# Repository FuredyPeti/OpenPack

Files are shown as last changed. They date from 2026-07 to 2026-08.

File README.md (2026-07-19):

# OpenPack

**An open-source, field-serviceable USB-C PD power bank built around standard 18650 cells.**

OpenPack is a portable battery pack designed to be repaired, not replaced. Instead of a sealed pouch cell, it holds six user-replaceable 18650 cells in a 2P3S configuration, so when capacity fades you swap cells instead of throwing the whole device away. It's built around a single PCB (`BATMOD_V1p0`) housed in a 3D-printed, military-styled enclosure with a CNC-machined aluminum front panel.

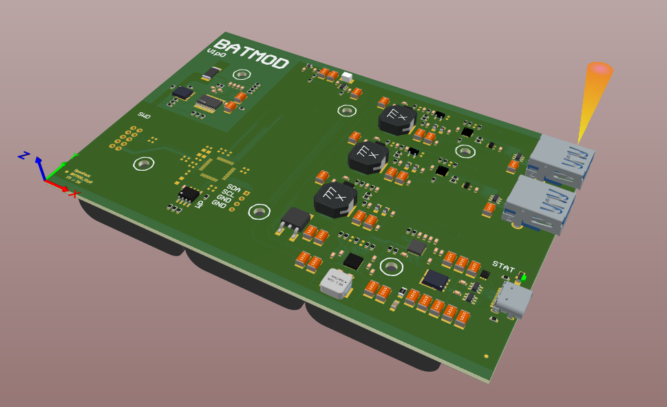
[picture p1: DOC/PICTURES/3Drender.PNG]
OpenPack_BATMOD_V1p0


---

## Highlights

- **6x 18650 cells in swappable holders** — 2P3S pack, use any cell you like
- **100 W USB-C PD port** — sink or source up to 20 V / 5 A
- **Two fixed 5 V / 2 A USB-A ports** for everyday device charging
- **Dedicated hardware balancing and protection** for the 3S pack
- **Single-board design** (`BATMOD_V1p0`) — everything lives on one PCB
- **3D-printed enclosure** with a machined aluminum port plate
- **Fully open source** — schematics, PCB, and mechanical files included

---

## Specifications

| | |
|---|---|
| Cell configuration | 2P3S (6x 18650, user-supplied, socketed in holders) |
| USB-C port | USB PD, sink/source up to 20 V @ 5 A (100 W) |
| USB-A port 1 | Fixed 5 V, up to 2 A |
| USB-A port 2 | Fixed 5 V, up to 2 A |
| Charging input | USB-C only (USB-A ports are output-only) |
| PCB | BATMOD_V1p0 | 94mm x 140mm
| Enclosure | 3D-printed body, CNC-machined aluminum front panel |

---

## Electronics

### USB-C PD port — TPS25751SRSMR

The USB-C port is driven by TI's **TPS25751**, a standalone USB Type-C and Power Delivery controller with integrated power switches. It's USB-IF certified for PD 3.1 and handles the full Type-C/PD negotiation stack on its own, so the port can act as either a sink or a source and negotiate up to 20 V at 5 A (100 W). The chip also includes dead-battery boot support (it can power itself from VBUS with no cell installed) and integrated protection — reverse current, over/undervoltage, and inrush current limiting — on its power paths. It also natively integrates control signaling for external battery-charger ICs like the BQ25798 below, which is how it hands off charging duties to the rest of the board.

### Battery charging — BQ25798RQMR

Charging is managed by the **BQ25798**, a 5 A, I2C-controlled buck-boost charger for 1- to 4-cell Li-ion/Li-poly packs. It runs a wide 3.6 V–24 V input range, is USB PD-compliant, and automatically switches between buck, boost, and buck-boost modes depending on input and battery voltage — useful given how much VBUS can swing across different PD sources. It also includes input current optimization (ICO) and MPPT for oddball or current-limited sources.

### Battery protection & cell balancing — BQ7791500PWT (BQ77915)

Pack-level safety and balancing is handled by the **BQ77915**, a stackable primary protector purpose-built for 3S–5S packs. It runs autonomous passive cell balancing (up to 50 mA) without needing a microcontroller, on top of the usual overvoltage/undervoltage/overcurrent/overtemperature protection suite — matched here to the pack's 3S configuration.

### USB-A output ports — TPS2547RTER

The two USB-A ports are each driven by a **TPS2547**, a USB charging port controller with an integrated 3 A power switch and D+/D− load detection. It presents the correct charging signatures (BC1.2 and common non-BC1.2 legacy schemes) so phones, tablets, and other USB-A devices auto-detect the port and charge at their expected rate. On OpenPack these are configured for a fixed 5 V output, capped at 2 A, and are output-only — they cannot be used to charge the internal pack.

---

## Mechanical design

Everything lives on one board — **BATMOD_V1p0** — with the six 18650 holders mounted on one side of the PCB. The board drops into a 3D-printed enclosure styled after military-grade equipment, and the front plate, where the USB-C and both USB-A ports live, is CNC-machined from aluminum rather than printed, both for durability at the connectors and for the finish.

---

## Repository contents

- `/HW` — schematics and PCB design files for BATMOD_V1p0
- `/MECH` — 3D-printable enclosure and aluminum front-plate machining files
- `/SYS` — assembly notes and reference material

---

## Safety note

This project involves user-configurable Li-ion packs and mains-adjacent charge currents. If you build one, use protected/authentic cells, verify balancing and protection behavior before first full charge, and don't leave a pack charging unattended until you've validated your build.

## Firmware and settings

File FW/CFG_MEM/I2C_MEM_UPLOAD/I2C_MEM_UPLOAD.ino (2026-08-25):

#include <Wire.h>

const char tps25750x_fullFlash_i2c_array[] = {
0x00, 0x08, 0x00, 0x00, 0xff, 0xff, 0xff, 0xff, 0xff, 0xff, 0xff, 0xff, 0xff, 0xff, 0xff, 0xff, 
0xff, 0xff, 0xff, 0xff, 0xff, 0xff, 0xff, 0xff, 0xff, 0xff, 0xff, 0xff, 0xff, 0xff, 0xff, 0xff, 
0xff, 0xff, 0xff, 0xff, 0xff, 0xff, 0xff, 0xff, 0xff, 0xff, 0xff, 0xff, 0xff, 0xff, 0xff, 0xff, 
0xff, 0xff, 0xff, 0xff, 0xff, 0xff, 0xff, 0xff, 0xff, 0xff, 0xff, 0xff, 0xff, 0xff, 0xff, 0xff, 
0xff, 0xff, 0xff, 0xff, 0xff, 0xff, 0xff, 0xff, 0xff, 0xff, 0xff, 0xff, 0xff, 0xff, 0xff, 0xff, 
0xff, 0xff, 0xff, 0xff, 0xff, 0xff, 0xff, 0xff, 0xff, 0xff, 0xff, 0xff, 0xff, 0xff, 0xff, 0xff, 
0xff, 0xff, 0xff, 0xff, 0xff, 0xff, 0xff, 0xff, 0xff, 0xff, 0xff, 0xff, 0xff, 0xff, 0xff, 0xff, 
0xff, 0xff, 0xff, 0xff, 0xff, 0xff, 0xff, 0xff, 0xff, 0xff, 0xff, 0xff, 0xff, 0xff, 0xff, 0xff, 
0xff, 0xff, 0xff, 0xff, 0xff, 0xff, 0xff, 0xff, 0xff, 0xff, 0xff, 0xff, 0xff, 0xff, 0xff, 0xff, 
0xff, 0xff, 0xff, 0xff, 0xff, 0xff, 0xff, 0xff, 0xff, 0xff, 0xff, 0xff, 0xff, 0xff, 0xff, 0xff, 
0xff, 0xff, 0xff, 0xff, 0xff, 0xff, 0xff, 0xff, 0xff, 0xff, 0xff, 0xff, 0xff, 0xff, 0xff, 0xff, 
0xff, 0xff, 0xff, 0xff, 0xff, 0xff, 0xff, 0xff, 0xff, 0xff, 0xff, 0xff, 0xff, 0xff, 0xff, 0xff, 
0xff, 0xff, 0xff, 0xff, 0xff, 0xff, 0xff, 0xff, 0xff, 0xff, 0xff, 0xff, 0xff, 0xff, 0xff, 0xff, 
0xff, 0xff, 0xff, 0xff, 0xff, 0xff, 0xff, 0xff, 0xff, 0xff, 0xff, 0xff, 0xff, 0xff, 0xff, 0xff, 
0xff, 0xff, 0xff, 0xff, 0xff, 0xff, 0xff, 0xff, 0xff, 0xff, 0xff, 0xff, 0xff, 0xff, 0xff, 0xff, 
0xff, 0xff, 0xff, 0xff, 0xff, 0xff, 0xff, 0xff, 0xff, 0xff, 0xff, 0xff, 0xff, 0xff, 0xff, 0xff, 
0xff, 0xff, 0xff, 0xff, 0xff, 0xff, 0xff, 0xff, 0xff, 0xff, 0xff, 0xff, 0xff, 0xff, 0xff, 0xff, 
0xff, 0xff, 0xff, 0xff, 0xff, 0xff, 0xff, 0xff, 0xff, 0xff, 0xff, 0xff, 0xff, 0xff, 0xff, 0xff, 
0xff, 0xff, 0xff, 0xff, 0xff, 0xff, 0xff, 0xff, 0xff, 0xff, 0xff, 0xff, 0xff, 0xff, 0xff, 0xff, 
0xff, 0xff, 0xff, 0xff, 0xff, 0xff, 0xff, 0xff, 0xff, 0xff, 0xff, 0xff, 0xff, 0xff, 0xff, 0xff, 
0xff, 0xff, 0xff, 0xff, 0xff, 0xff, 0xff, 0xff, 0xff, 0xff, 0xff, 0xff, 0xff, 0xff, 0xff, 0xff, 
0xff, 0xff, 0xff, 0xff, 0xff, 0xff, 0xff, 0xff, 0xff, 0xff, 0xff, 0xff, 0xff, 0xff, 0xff, 0xff, 
0xff, 0xff, 0xff, 0xff, 0xff, 0xff, 0xff, 0xff, 0xff, 0xff, 0xff, 0xff, 0xff, 0xff, 0xff, 0xff, 
0xff, 0xff, 0xff, 0xff, 0xff, 0xff, 0xff, 0xff, 0xff, 0xff, 0xff, 0xff, 0xff, 0xff, 0xff, 0xff, 
0xff, 0xff, 0xff, 0xff, 0xff, 0xff, 0xff, 0xff, 0xff, 0xff, 0xff, 0xff, 0xff, 0xff, 0xff, 0xff, 
0xff, 0xff, 0xff, 0xff, 0xff, 0xff, 0xff, 0xff, 0xff, 0xff, 0xff, 0xff, 0xff, 0xff, 0xff, 0xff, 
0xff, 0xff, 0xff, 0xff, 0xff, 0xff, 0xff, 0xff, 0xff, 0xff, 0xff, 0xff, 0xff, 0xff, 0xff, 0xff, 
0xff, 0xff, 0xff, 0xff, 0xff, 0xff, 0xff, 0xff, 0xff, 0xff, 0xff, 0xff, 0xff, 0xff, 0xff, 0xff, 
0xff, 0xff, 0xff, 0xff, 0xff, 0xff, 0xff, 0xff, 0xff, 0xff, 0xff, 0xff, 0xff, 0xff, 0xff, 0xff, 
0xff, 0xff, 0xff, 0xff, 0xff, 0xff, 0xff, 0xff, 0xff, 0xff, 0xff, 0xff, 0xff, 0xff, 0xff, 0xff, 
0xff, 0xff, 0xff, 0xff, 0xff, 0xff, 0xff, 0xff, 0xff, 0xff, 0xff, 0xff, 0xff, 0xff, 0xff, 0xff, 
0xff, 0xff, 0xff, 0xff, 0xff, 0xff, 0xff, 0xff, 0xff, 0xff, 0xff, 0xff, 0xff, 0xff, 0xff, 0xff, 
0xff, 0xff, 0xff, 0xff, 0xff, 0xff, 0xff, 0xff, 0xff, 0xff, 0xff, 0xff, 0xff, 0xff, 0xff, 0xff, 
0xff, 0xff, 0xff, 0xff, 0xff, 0xff, 0xff, 0xff, 0xff, 0xff, 0xff, 0xff, 0xff, 0xff, 0xff, 0xff, 
0xff, 0xff, 0xff, 0xff, 0xff, 0xff, 0xff, 0xff, 0xff, 0xff, 0xff, 0xff, 0xff, 0xff, 0xff, 0xff, 
0xff, 0xff, 0xff, 0xff, 0xff, 0xff, 0xff, 0xff, 0xff, 0xff, 0xff, 0xff, 0xff, 0xff, 0xff, 0xff, 
0xff, 0xff, 0xff, 0xff, 0xff, 0xff, 0xff, 0xff, 0xff, 0xff, 0xff, 0xff, 0xff, 0xff, 0xff, 0xff, 
0xff, 0xff, 0xff, 0xff, 0xff, 0xff, 0xff, 0xff, 0xff, 0xff, 0xff, 0xff, 0xff, 0xff, 0xff, 0xff, 
0xff, 0xff, 0xff, 0xff, 0xff, 0xff, 0xff, 0xff, 0xff, 0xff, 0xff, 0xff, 0xff, 0xff, 0xff, 0xff, 
0xff, 0xff, 0xff, 0xff, 0xff, 0xff, 0xff, 0xff, 0xff, 0xff, 0xff, 0xff, 0xff, 0xff, 0xff, 0xff, 
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


#define EEPROM_I2C_ADDRESS 0x50  // I2C address of EEPROM
#define PAGE_SIZE 64             // Page size in bytes
#define TOTAL_SIZE 32768         // Total EEPROM size (256Kbit = 32KB) - adjust as needed
#define WRITE_DELAY 30           // Write cycle time in ms (typ. 5ms, typ. 10ms max)

// Configuration
#define ENABLE_VERIFICATION true
#define ENABLE_VERBOSE_LOGGING true

// ============================================================================
// EEPROM Write Function - Handles page boundaries
// ============================================================================
bool EEPROM_WriteBytes(uint16_t memoryAddress, uint8_t* data, uint16_t length) {
    uint16_t bytesWritten = 0;

    while (bytesWritten < length) {
        // Calculate remaining space in current page
        uint16_t pageOffset = memoryAddress % PAGE_SIZE;
        uint16_t maxWriteInPage = PAGE_SIZE - pageOffset;

        // Determine how many bytes to write in this iteration
        uint16_t bytesToTransfer = length - bytesWritten;
        if (bytesToTransfer > maxWriteInPage) {
            bytesToTransfer = maxWriteInPage;
        }

        // Start I2C transmission
        Wire.beginTransmission(EEPROM_I2C_ADDRESS);

        // Send 16-bit memory address (MSB first, then LSB)
        Wire.write((uint8_t)(memoryAddress >> 8));
        Wire.write((uint8_t)(memoryAddress & 0xFF));

        // Send data bytes
        for (uint16_t i = 0; i < bytesToTransfer; i++) {
            Wire.write(data[bytesWritten + i]);
        }

        // End transmission and check for errors
        uint8_t error = Wire.endTransmission();
        if (error != 0) {
            Serial.print("I2C Error at address 0x");
            Serial.print(memoryAddress, HEX);
            Serial.print(": ");
            printI2CError(error);
            return false;
        }

        // CRITICAL: Wait for internal write cycle to complete
        delay(WRITE_DELAY);

        // Update counters
        memoryAddress += bytesToTransfer;
        bytesWritten += bytesToTransfer;
    }

    return true;
}

// ============================================================================
// EEPROM Read Function - Verify written data
// ============================================================================
bool EEPROM_ReadBytes(uint16_t memoryAddress, uint8_t* data, uint16_t length) {
    uint16_t bytesRead = 0;

    while (bytesRead < length) {
        // Set the memory address we want to read from
        Wire.beginTransmission(EEPROM_I2C_ADDRESS);
        Wire.write((uint8_t)(memoryAddress >> 8));
        Wire.write((uint8_t)(memoryAddress & 0xFF));
        uint8_t error = Wire.endTransmission();

        if (error != 0) {
            Serial.print("I2C Error during read address setup at 0x");
            Serial.print(memoryAddress, HEX);
            Serial.print(": ");
            printI2CError(error);
            return false;
        }

        // Read up to 32 bytes per request (many I2C devices have small RX buffers)
        uint16_t bytesToRead = length - bytesRead;
        if (bytesToRead > 32) {
            bytesToRead = 32;
        }

        // Request data
        uint8_t bytesAvailable = Wire.requestFrom(EEPROM_I2C_ADDRESS, (int)bytesToRead);

        if (bytesAvailable != bytesToRead) {
            Serial.print("I2C Read mismatch at 0x");
            Serial.print(memoryAddress, HEX);
            Serial.print(" - requested ");
            Serial.print(bytesToRead);
            Serial.print(" got ");
            Serial.println(bytesAvailable);
            return false;
        }

        // Read bytes into buffer
        for (uint16_t i = 0; i < bytesAvailable; i++) {
            data[bytesRead + i] = Wire.read();
        }

        bytesRead += bytesAvailable;
        memoryAddress += bytesAvailable;
    }

    return true;
}

// ============================================================================
// Verification Function - Compare written data with original
// ============================================================================
bool EEPROM_VerifyBytes(uint16_t memoryAddress, uint8_t* expectedData, uint16_t length) {
    uint8_t readBuffer[64];
    uint16_t bytesVerified = 0;

    while (bytesVerified < length) {
        uint16_t bytesToCheck = length - bytesVerified;
        if (bytesToCheck > 64) {
            bytesToCheck = 64;
        }

        // Read from EEPROM
        if (!EEPROM_ReadBytes(memoryAddress + bytesVerified, readBuffer, bytesToCheck)) {
            Serial.print("Verification read failed at address 0x");
            Serial.println(memoryAddress + bytesVerified, HEX);
            return false;
        }

        // Compare bytes
        for (uint16_t i = 0; i < bytesToCheck; i++) {
            if (readBuffer[i] != expectedData[bytesVerified + i]) {
                Serial.print("Verification MISMATCH at address 0x");
                Serial.print(memoryAddress + bytesVerified + i, HEX);
                Serial.print(" - Expected: 0x");
                Serial.print(expectedData[bytesVerified + i], HEX);
                Serial.print(" Got: 0x");
                Serial.println(readBuffer[i], HEX);
                return false;
            }
        }

        bytesVerified += bytesToCheck;
    }

    return true;
}

// ============================================================================
// Utility Functions
// ============================================================================
void printI2CError(uint8_t error) {
    switch(error) {
        case 0: Serial.println("Success"); break;
        case 1: Serial.println("Data too long for buffer"); break;
        case 2: Serial.println("NACK on address"); break;
        case 3: Serial.println("NACK on data"); break;
        case 4: Serial.println("Other error"); break;
        case 5: Serial.println("Timeout"); break;
        default: Serial.println("Unknown error"); break;
    }
}

void printHex(uint8_t value) {
    if (value < 0x10) Serial.print("0");
    Serial.print(value, HEX);
}

// ============================================================================
// Setup - Flash the EEPROM with data and verify
// ============================================================================
void setup() {
    Serial.begin(115200);
    delay(500); // Wait for serial to initialize

    Serial.println("\n=== ESP32 EEPROM I2C Programmer ===");
    Serial.println("Initializing I2C...");

    Wire.begin(21, 22); // SDA = GPIO 21, SCL = GPIO 22
    Wire.setClock(400000); // 400 kHz I2C speed

    // Calculate total data to write
    size_t dataSize = sizeof(tps25750x_fullFlash_i2c_array) / sizeof(tps25750x_fullFlash_i2c_array[0]);
    uint16_t totalPages = (dataSize + PAGE_SIZE - 1) / PAGE_SIZE; // Round up

    Serial.print("Data size: ");
    Serial.print(dataSize);
    Serial.println(" bytes");
    Serial.print("Pages to write: ");
    Serial.println(totalPages);
    Serial.println();

    uint16_t regaddress = 0;
    uint8_t Data[PAGE_SIZE];
    uint16_t pageCount = 0;
    uint32_t startTime = millis();

    // ========== WRITE PHASE ==========
    Serial.println("--- WRITE PHASE ---");

    for (pageCount = 0; pageCount < totalPages; pageCount++) {
        // Determine how many bytes to write in this page
        uint16_t bytesToWrite = dataSize - regaddress;
        if (bytesToWrite > PAGE_SIZE) {
            bytesToWrite = PAGE_SIZE;
        }

        // Copy data to temporary buffer
        for (int i = 0; i < bytesToWrite; i++) {
            Data[i] = (uint8_t)tps25750x_fullFlash_i2c_array[regaddress + i];
        }

        // Write page
        if (EEPROM_WriteBytes(regaddress, Data, bytesToWrite)) {
            if (ENABLE_VERBOSE_LOGGING) {
                Serial.print("Page ");
                Serial.print(pageCount + 1);
                Serial.print("/");
                Serial.print(totalPages);
                Serial.print(" written at address 0x");
                Serial.print(regaddress, HEX);
                Serial.print(" (");
                Serial.print(bytesToWrite);
                Serial.println(" bytes)");
            }
        } else {
            Serial.print("ERROR writing page ");
            Serial.print(pageCount + 1);
            Serial.print(" at address 0x");
            Serial.println(regaddress, HEX);
            goto errorExit;
        }

        regaddress += bytesToWrite;
    }

    Serial.println("Write phase completed!\n");

    // ========== VERIFICATION PHASE ==========
    if (ENABLE_VERIFICATION) {
        Serial.println("--- VERIFICATION PHASE ---");
        regaddress = 0;
        uint16_t failedPages = 0;

        for (pageCount = 0; pageCount < totalPages; pageCount++) {
            uint16_t bytesToVerify = dataSize - (pageCount * PAGE_SIZE);
            if (bytesToVerify > PAGE_SIZE) {
                bytesToVerify = PAGE_SIZE;
            }

            // Get original data
            for (int i = 0; i < bytesToVerify; i++) {
                Data[i] = (uint8_t)tps25750x_fullFlash_i2c_array[regaddress + i];
            }

            // Verify
            if (EEPROM_VerifyBytes(regaddress, Data, bytesToVerify)) {
                if (ENABLE_VERBOSE_LOGGING) {
                    Serial.print("Page ");
                    Serial.print(pageCount + 1);
                    Serial.print("/");
                    Serial.print(totalPages);
                    Serial.print(" verified at address 0x");
                    Serial.println(regaddress, HEX);
                }
            } else {
                Serial.print("VERIFICATION FAILED on page ");
                Serial.print(pageCount + 1);
                Serial.print(" at address 0x");
                Serial.println(regaddress, HEX);
                failedPages++;
            }

            regaddress += bytesToVerify;
        }

        Serial.println();
        if (failedPages == 0) {
            Serial.println("✓ ALL PAGES VERIFIED SUCCESSFULLY!");
        } else {
            Serial.print("✗ ");
            Serial.print(failedPages);
            Serial.println(" page(s) failed verification!");
            goto errorExit;
        }
    }

    // ========== SUCCESS ==========
    {
        uint32_t elapsed = millis() - startTime;
        Serial.println("\n=== PROGRAMMING COMPLETE ===");
        Serial.print("Total time: ");
        Serial.print(elapsed);
        Serial.println(" ms");
        Serial.print("Data rate: ");
        Serial.print((dataSize * 1000) / elapsed);
        Serial.println(" bytes/sec");
    }
    return;

    // ========== ERROR EXIT ==========
    errorExit:
    Serial.println("\n✗ PROGRAMMING FAILED!");
    Serial.println("Check:");
    Serial.println("  - I2C address (default 0x50)");
    Serial.println("  - I2C pull-up resistors (usually 4.7kΩ)");
    Serial.println("  - EEPROM chip connections");
    Serial.println("  - EEPROM write protection (WP pin)");
}

void loop() {
    // Empty - all work done in setup
}

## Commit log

2026-07-12 First HW commit, started to work on SCH
    [OpenPack_BATMOD_V1p0.PrjPcb, OpenPack_BATMOD_V1p0_CHRG.SchDoc, OpenPack_BATMOD_V1p0_FRP.SchDoc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]
2026-07-13 Working on manager, battery, cell balancer, USBA ports and main page
    [OpenPack_BATMOD_V1p0.PrjPcb, OpenPack_BATMOD_V1p0_BAT.SchDoc, OpenPack_BATMOD_V1p0_CHRG.SchDoc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]
2026-07-14 Overall schematic progress 90%
    [OpenPack_BATMOD_V1p0_BAT.SchDoc, OpenPack_BATMOD_V1p0_CHRG.SchDoc, OpenPack_BATMOD_V1p0_MAIN.SchDoc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]
2026-07-15 SCH finishing, PCB start
    [OpenPack_BATMOD_V1p0.PrjPcb, OpenPack_BATMOD_V1p0_BAT.SchDoc, OpenPack_BATMOD_V1p0_CHRG.SchDoc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]
2026-07-15 More work on PCB
    [OpenPack_BATMOD_V1p0.PrjPcb, OpenPack_BATMOD_V1p0_CHRG.SchDoc, OpenPack_BATMOD_V1p0_PWR.SchDoc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]
2026-07-16 PCB progress
    [OpenPack_BATMOD_V1p0_MAN.SchDoc, OpenPack_BATMOD_V1p0_USBA.SchDoc]
2026-07-19 PCB 95%
    [OpenPack_BATMOD_V1p0.PrjPcb, OpenPack_BATMOD_V1p0_BAT.SchDoc, OpenPack_BATMOD_V1p0_CHRG.SchDoc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]
2026-07-19 PCB ready
    [OpenPack_BATMOD_V1p0.PrjPcb, OpenPack_BATMOD_V1p0_FRP.SchDoc, OpenPack_BATMOD_V1p0_MCU.SchDoc]
2026-07-19 ReadMe modified, PCB save
2026-07-20 DRC, starting working on BOM, final SCH checks done
    [OpenPack_BATMOD_V1p0.PrjPcb, OpenPack_BATMOD_V1p0_BAT.SchDoc, OpenPack_BATMOD_V1p0_CHRG.SchDoc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]
2026-07-27 Re-linking PCB lib
    [OpenPack_BATMOD_V1p0.PrjPcb]
2026-08-16 Board bring up
    [OpenPack_BATMOD_V1p0.PcbDoc, OpenPack_BATMOD_V1p0_BAT.SchDoc, OpenPack_BATMOD_V1p0_CHRG.SchDoc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]
2026-08-16 Onboard memory programming
    [Configurator.txt]
2026-08-18 FRP fix
    [OpenPack_BATMOD_V1p0_FRP.SchDoc]
2026-08-18 Starting to work on new version
    [OpenPack_BATMOD_V2p0.PcbDoc, OpenPack_BATMOD_V2p0.PrjPcb, OpenPack_BATMOD_V2p0_BAT.SchDoc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]
2026-08-21 Fixing things on SCH, working op PCB
    [OpenPack_BATMOD_V2p0.PcbDoc, OpenPack_BATMOD_V2p0.PrjPcb, OpenPack_BATMOD_V2p0_BAT.SchDoc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]
2026-08-25 reduced charge current to 2A
2026-09-01 changes ready
    [OpenPack_BATMOD_V2p0.PcbDoc, OpenPack_BATMOD_V2p0.PrjPcb, OpenPack_BATMOD_V2p0_CHRG.SchDoc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]
